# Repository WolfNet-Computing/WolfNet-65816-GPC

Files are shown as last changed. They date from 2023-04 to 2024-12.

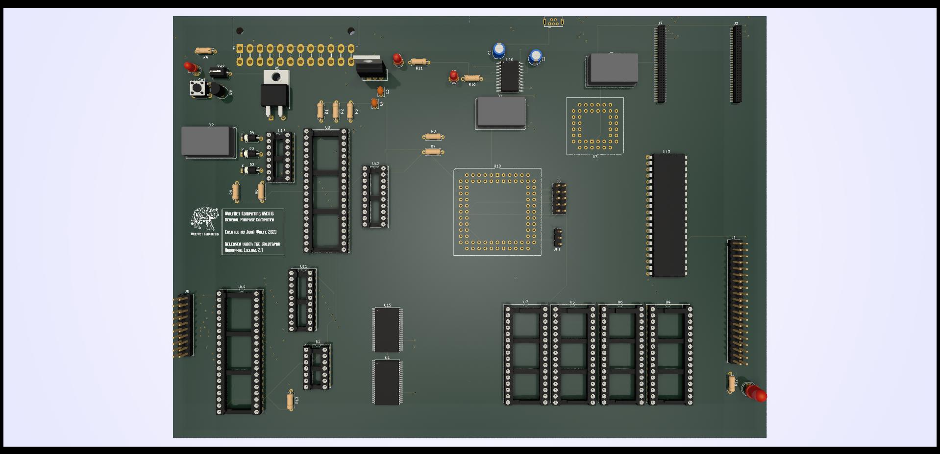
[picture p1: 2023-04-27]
Motherboard.jpg

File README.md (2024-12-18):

# WolfNet-65816-GPC
 WolfNet Computing 65816 based General Purpose Computer

Intended as an upgrade to the WolfNet-65C02-WBC, this computer is more general purpose in design and nature. Text-based USB-Serial control makes connecting to it easy. You don't even need a spare screen or keyboard. Plug it in to your computer, power it on and away you go.

Features:  
 - 65C816 Based design
 - USB Type-B Connnector, MCP2200 and SC28L91 for I/O (Think keyboard, mouse and screen but as a program on your PC, connecting to the device.)
 - ATF1508AS Based Reprogrammable Address Decoder and DMA Controller
 - ATX 20-Pin Power Connector
 - 65-SIB Serial Interface Bus
 - 40-Pin IDE Connector for PATA HDDs
 - 16 MiB Flash ROM
 - 16 MiB SRAM
 - Built-in JTAG-ISP Header for ATF1508AS

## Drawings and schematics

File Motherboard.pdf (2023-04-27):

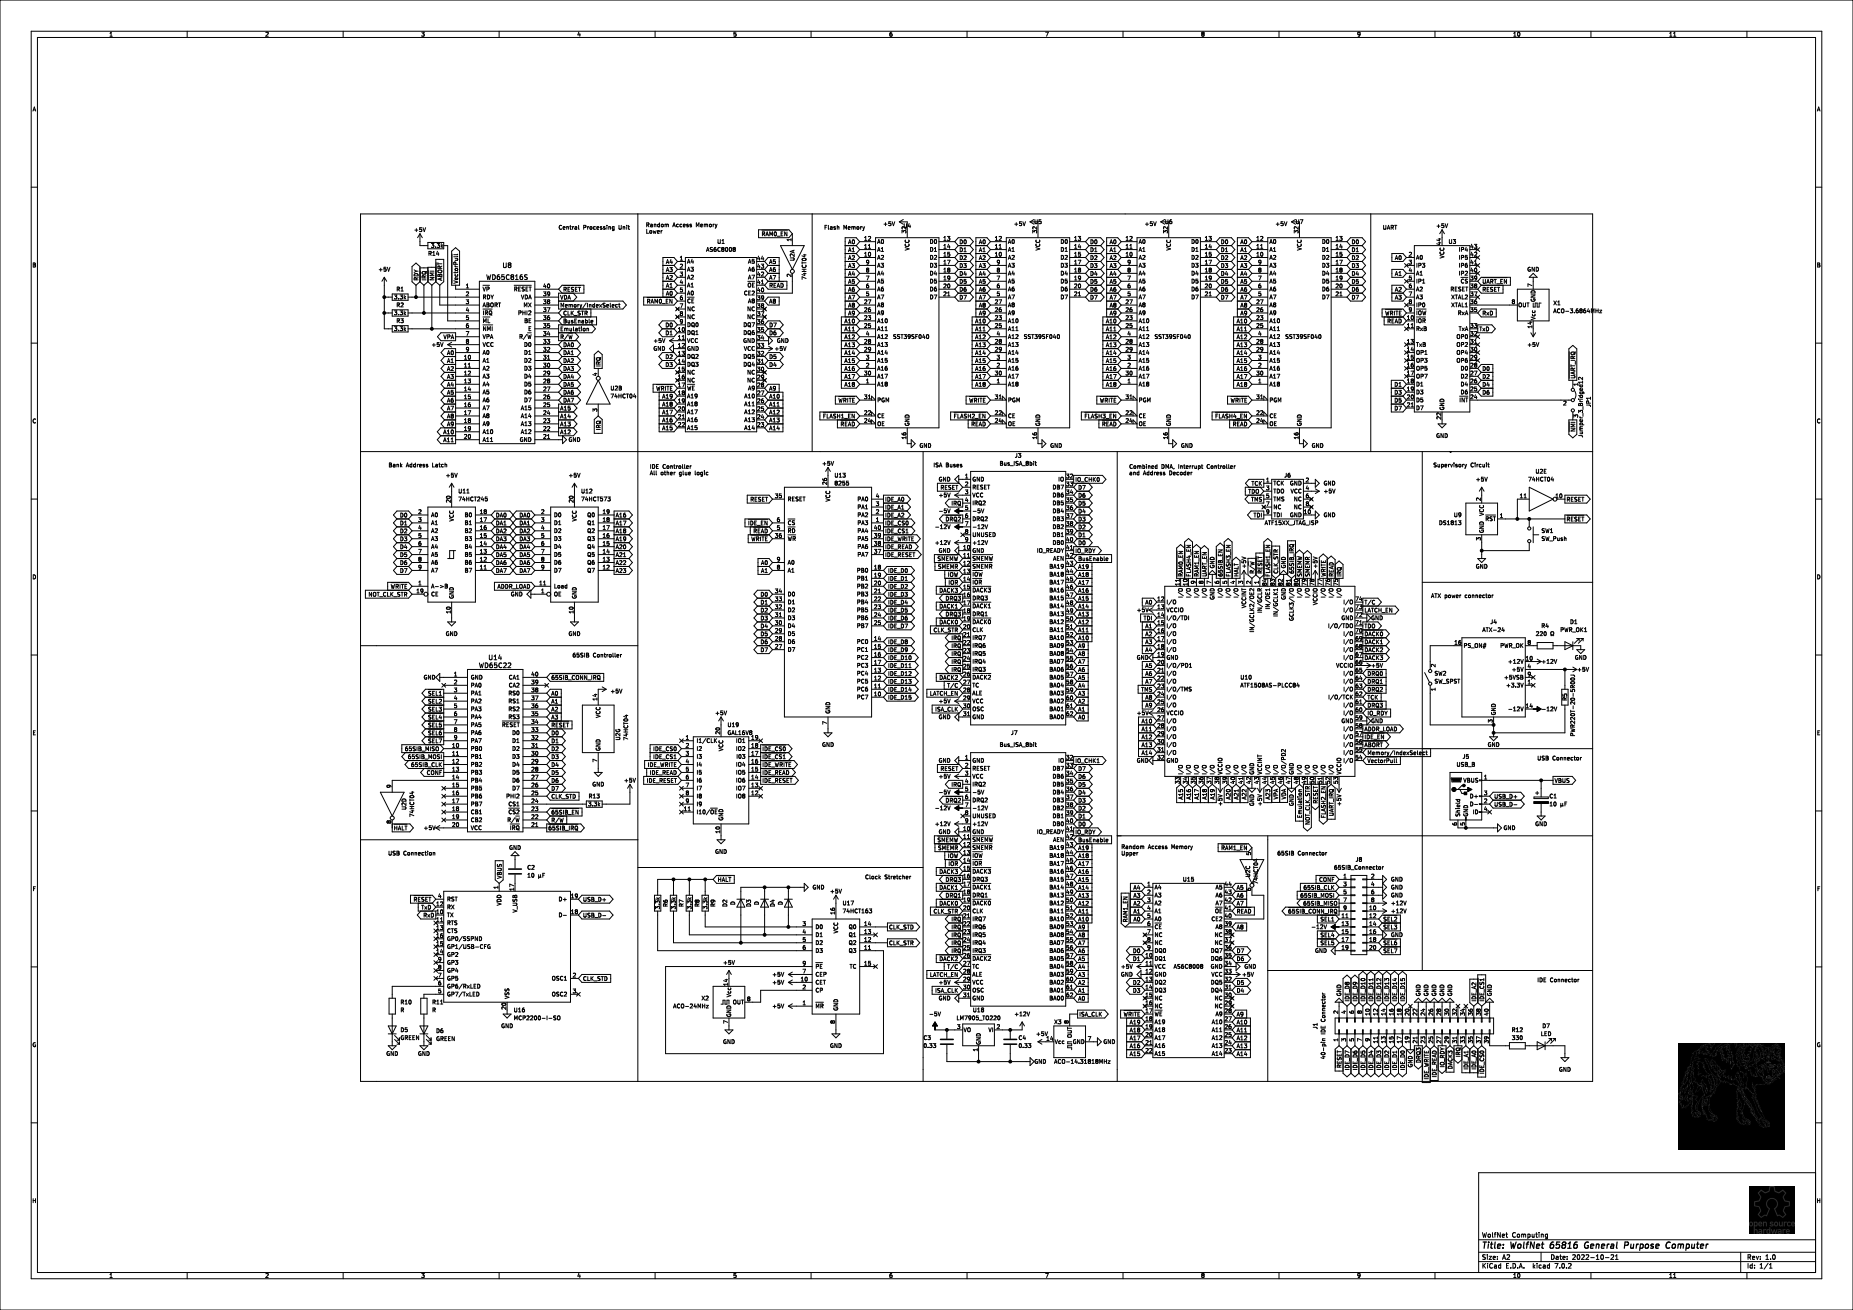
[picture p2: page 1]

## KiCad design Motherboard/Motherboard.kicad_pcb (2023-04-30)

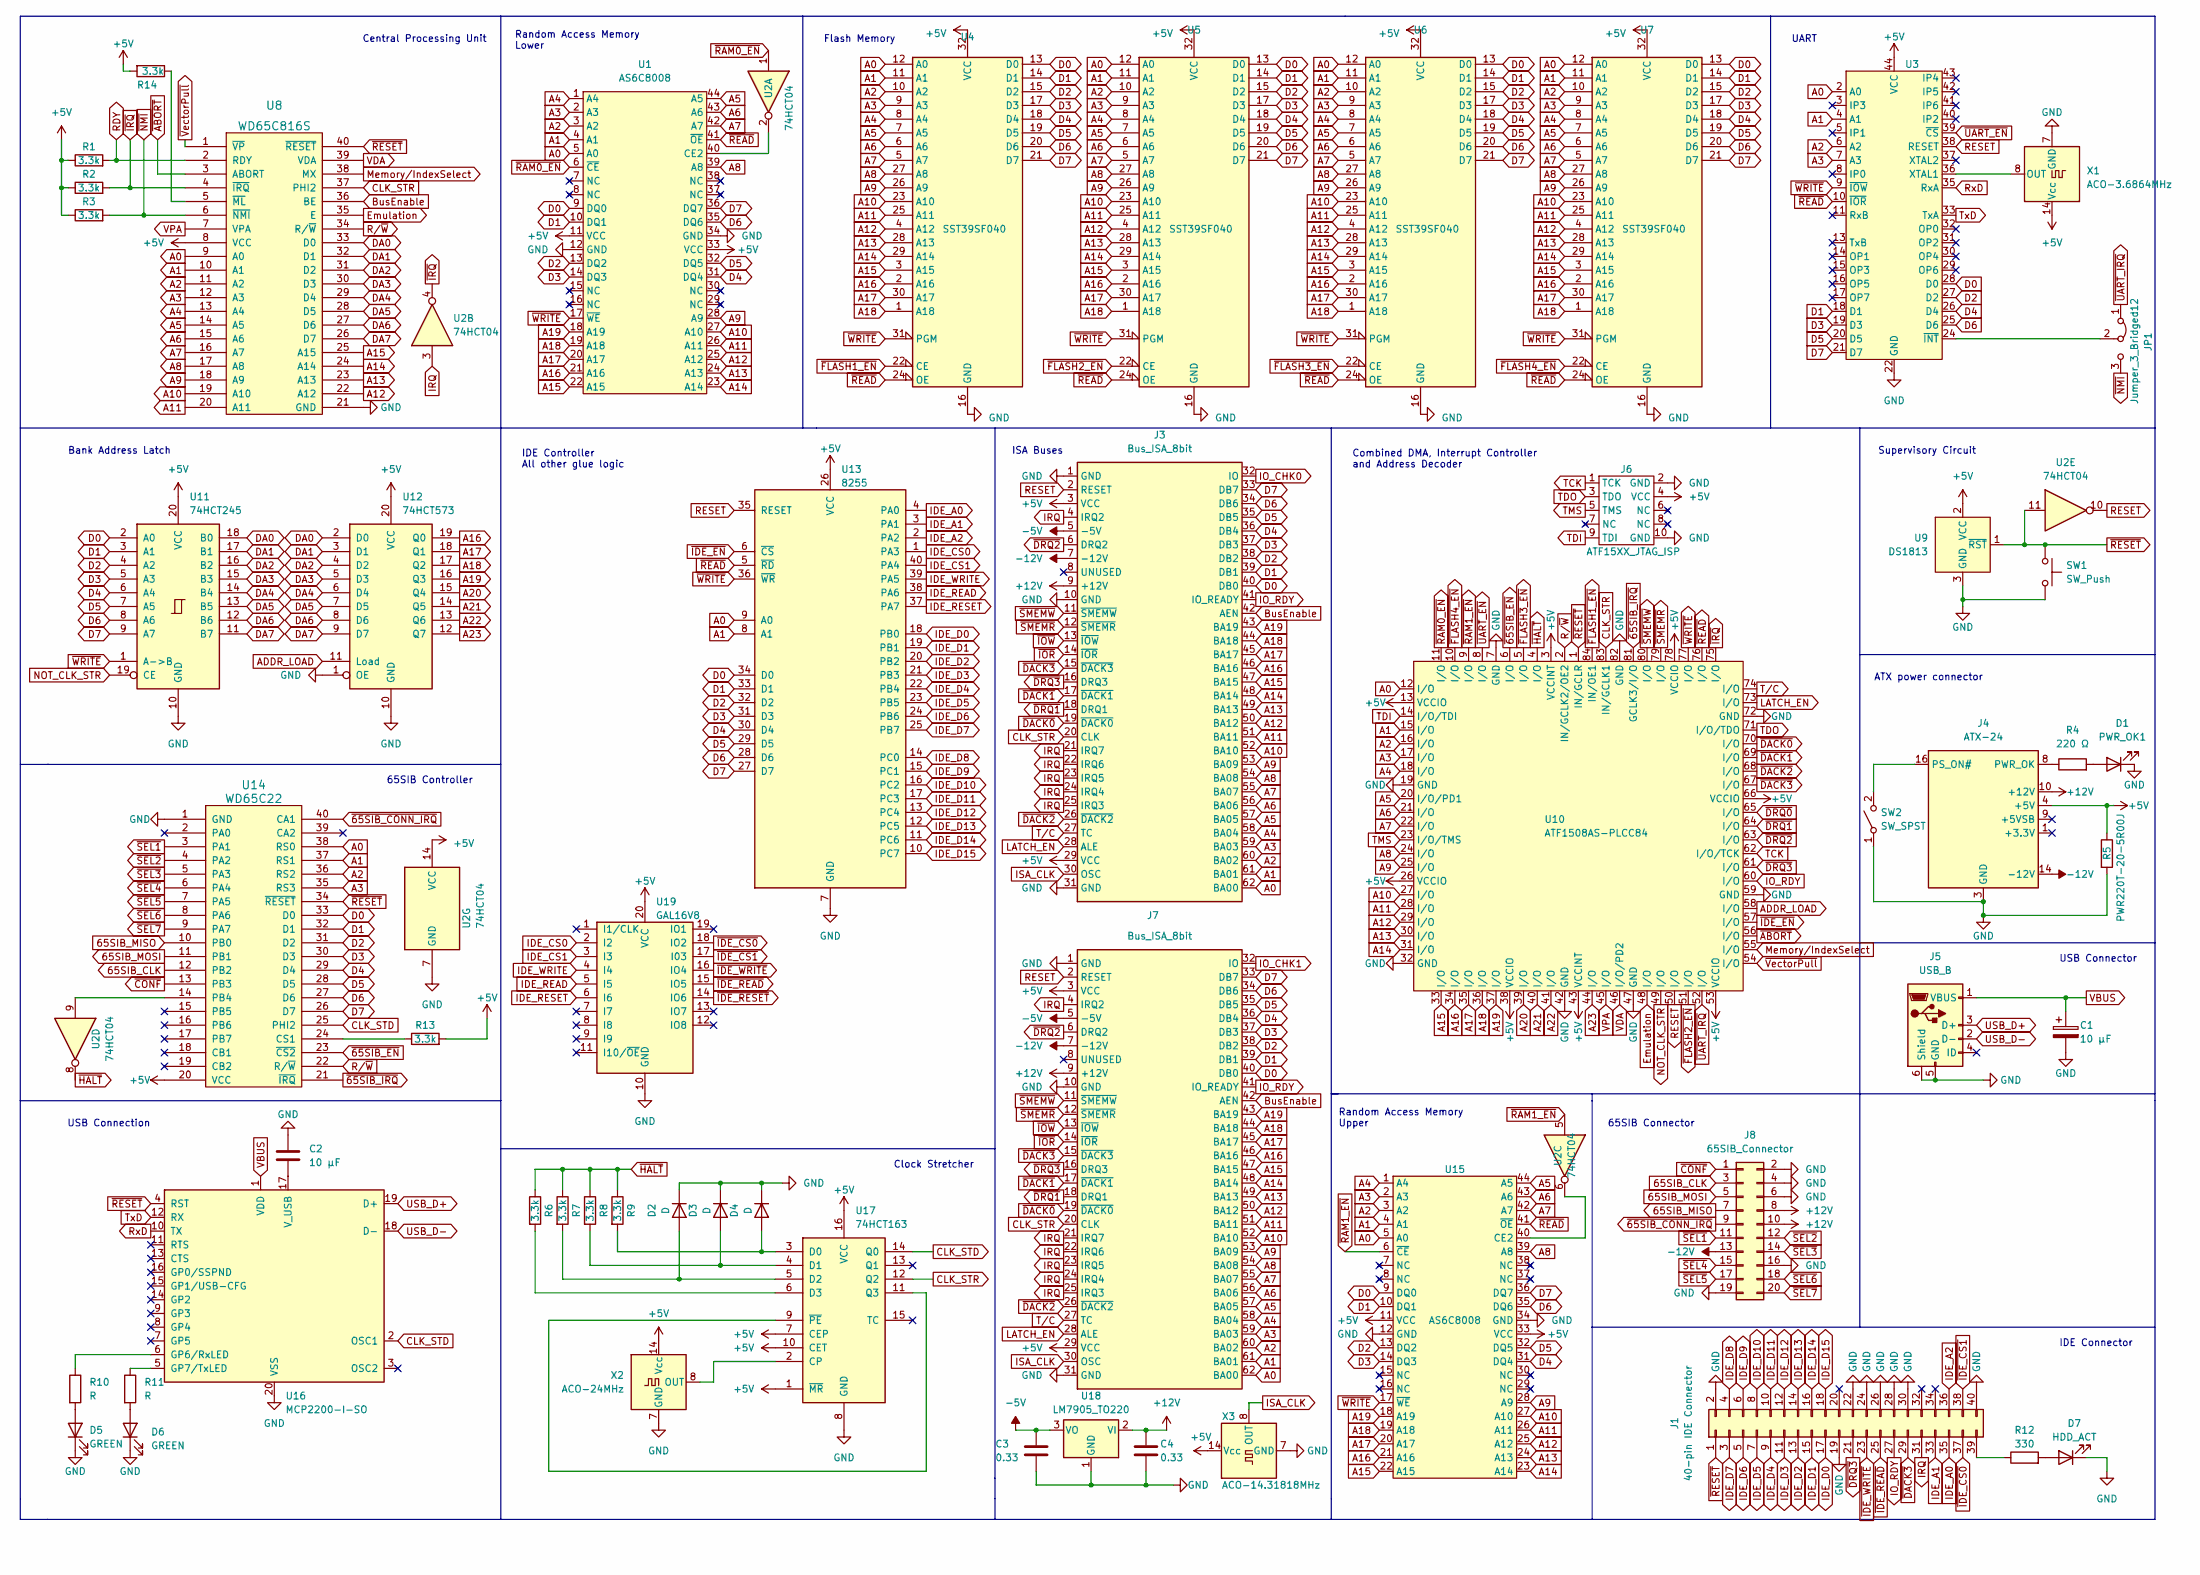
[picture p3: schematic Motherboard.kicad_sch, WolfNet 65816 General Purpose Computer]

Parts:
C1, C2: 10 µF; CP_Radial_D5.0mm_P2.50mm
C3, C4: 0.33; C_Disc_D3.8mm_W2.6mm_P2.50mm
D1: PWR_OK1; LED_D3.0mm
D2, D3, D4: D; D_A-405_P7.62mm_Horizontal
D5, D6: GREEN; LED_D3.0mm
D7: HDD_ACT; LED_D5.0mm
J1: 40-pin IDE Connector; PinHeader_2x20_P2.54mm_Vertical
J3, J7: Bus_ISA_8bit; PinSocket_2x31_P1.00mm_Vertical_SMD
J4: ATX-24; Molex_Mini-Fit_Jr_5569-24A2_2x12_P4.20mm_Horizontal
J5: USB_B; USB_Mini-B_Tensility_54-00023_Vertical
J6: ATF15XX_JTAG_ISP; PinHeader_2x05_P2.54mm_Vertical
J8: 65SIB_Connector; PinHeader_2x10_P2.54mm_Vertical
JP1: Jumper_3_Bridged12; PinHeader_1x03_P2.54mm_Vertical
R1, R2, R3, R6, R7, R8, R9, R13, R14: 3.3k; R_Axial_DIN0207_L6.3mm_D2.5mm_P7.62mm_Horizontal
R4: 220 Ω; R_Axial_DIN0207_L6.3mm_D2.5mm_P7.62mm_Horizontal
R5: PWR220T-20-5R00J; TO-220-2_Horizontal_TabDown
R10, R11: R; R_Axial_DIN0207_L6.3mm_D2.5mm_P7.62mm_Horizontal
R12: 330; R_Axial_DIN0207_L6.3mm_D2.5mm_P7.62mm_Horizontal
SW1: SW_Push; SW_PUSH_6mm
SW2: SW_SPST; SW_DIP_SPSTx01_Slide_6.7x4.1mm_W7.62mm_P2.54mm_LowProfile
U1, U15: AS6C8008; TSOP-II-44_10.16x18.41mm_P0.8mm
U2: 74HCT04; DIP-14_W7.62mm_Socket_LongPads
U3: PLCC-44_THT-Socket
U4, U5, U6, U7: SST39SF040; DIP-32_W15.24mm_Socket_LongPads
U8: WD65C816S; DIP-40_W15.24mm_Socket_LongPads
U9: DS1813; TO-92_Inline
U10: ATF1508AS-PLCC84; PLCC-84_THT-Socket
U11: 74HCT245; DIP-20_W7.62mm_Socket_LongPads
U12: 74HCT573; DIP-20_W7.62mm_Socket_LongPads
U13: 8255; DIP-40_W15.24mm
U14: WD65C22; DIP-40_W15.24mm_Socket_LongPads
U16: MCP2200-I-SO; SOIC-20W_7.5x12.8mm_P1.27mm
U17: 74HCT163; DIP-16_W7.62mm_Socket_LongPads
U18: LM7905_TO220; TO-220-3_Vertical
U19: GAL16V8; DIP-20_W7.62mm_Socket_LongPads
X1: ACO-3.6864MHz; Oscillator_DIP-14
X2: ACO-24MHz; Oscillator_DIP-14
X3: ACO-14.31818MHz; Oscillator_DIP-14

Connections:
65SIB_CLK: J8.3 (CLK), U14.12 (PB2)
65SIB_MISO: J8.7 (MISO), U14.10 (PB0)
65SIB_MOSI: J8.5 (MOSI), U14.11 (PB1)
+5V: J3.3 (VCC), J3.29 (VCC), J4.4 (+5V), J4.6 (+5V), J4.21 (+5V), J4.22 (+5V), J4.23 (+5V), J6.4 (VCC), J7.3 (VCC), J7.29 (VCC), R1.1, R2.1, R3.1, R5.1, R13.2, R14.2, U1.11 (VCC), U1.33 (VCC), U2.14 (VCC), U3.44 (VCC), U4.32 (VCC), U5.32 (VCC), U6.32 (VCC), U7.32 (VCC), U8.8 (VCC), U9.2 (VCC), U10.3 (VCCINT), U10.13 (VCCIO), U10.26 (VCCIO), U10.38 (VCCIO), U10.43 (VCCINT), U10.53 (VCCIO), U10.66 (VCCIO), U10.78 (VCCIO), U11.20 (VCC), U12.20 (VCC), U13.26 (VCC), U14.20 (VCC), U15.11 (VCC), U15.33 (VCC), U17.1 (~MR), U17.7 (CEP), U17.10 (CET), U17.16 (VCC), U19.20 (VCC), X1.14 (Vcc), X2.14 (Vcc), X3.14 (Vcc)
+12V: C4.1, J3.9 (+12V), J4.10 (+12V), J4.11 (+12V), J7.9 (+12V), J8.8 (12v), J8.10 (12v), U18.2 (VI)
-5V: C3.1, J3.5 (-5V), J7.5 (-5V), U18.3 (VO)
-12V: J3.7 (-12V), J4.14 (-12V), J7.7 (-12V), J8.13 (-12v)
A0: J3.62 (BA00), J7.62 (BA00), U1.5 (A0), U3.2 (A0), U4.12 (A0), U5.12 (A0), U6.12 (A0), U7.12 (A0), U8.9 (A0), U10.12 (I/O), U13.9 (A0), U14.38 (RS0), U15.5 (A0)
A1: J3.61 (BA01), J7.61 (BA01), U1.4 (A1), U3.4 (A1), U4.11 (A1), U5.11 (A1), U6.11 (A1), U7.11 (A1), U8.10 (A1), U10.15 (I/O), U13.8 (A1), U14.37 (RS1), U15.4 (A1)
A2: J3.60 (BA02), J7.60 (BA02), U1.3 (A2), U3.6 (A2), U4.10 (A2), U5.10 (A2), U6.10 (A2), U7.10 (A2), U8.11 (A2), U10.16 (I/O), U14.36 (RS2), U15.3 (A2)
A3: J3.59 (BA03), J7.59 (BA03), U1.2 (A3), U3.7 (A3), U4.9 (A3), U5.9 (A3), U6.9 (A3), U7.9 (A3), U8.12 (A3), U10.17 (I/O), U14.35 (RS3), U15.2 (A3)
A4: J3.58 (BA04), J7.58 (BA04), U1.1 (A4), U4.8 (A4), U5.8 (A4), U6.8 (A4), U7.8 (A4), U8.13 (A4), U10.18 (I/O), U15.1 (A4)
A5: J3.57 (BA05), J7.57 (BA05), U1.44 (A5), U4.7 (A5), U5.7 (A5), U6.7 (A5), U7.7 (A5), U8.14 (A5), U10.20 (I/O/PD1), U15.44 (A5)
A6: J3.56 (BA06), J7.56 (BA06), U1.43 (A6), U4.6 (A6), U5.6 (A6), U6.6 (A6), U7.6 (A6), U8.15 (A6), U10.21 (I/O), U15.43 (A6)
A7: J3.55 (BA07), J7.55 (BA07), U1.42 (A7), U4.5 (A7), U5.5 (A7), U6.5 (A7), U7.5 (A7), U8.16 (A7), U10.22 (I/O), U15.42 (A7)
A8: J3.54 (BA08), J7.54 (BA08), U1.39 (A8), U4.27 (A8), U5.27 (A8), U6.27 (A8), U7.27 (A8), U8.17 (A8), U10.24 (I/O), U15.39 (A8)
A9: J3.53 (BA09), J7.53 (BA09), U1.28 (A9), U4.26 (A9), U5.26 (A9), U6.26 (A9), U7.26 (A9), U8.18 (A9), U10.25 (I/O), U15.28 (A9)
A10: J3.52 (BA10), J7.52 (BA10), U1.27 (A10), U4.23 (A10), U5.23 (A10), U6.23 (A10), U7.23 (A10), U8.19 (A10), U10.27 (I/O), U15.27 (A10)
A11: J3.51 (BA11), J7.51 (BA11), U1.26 (A11), U4.25 (A11), U5.25 (A11), U6.25 (A11), U7.25 (A11), U8.20 (A11), U10.28 (I/O), U15.26 (A11)
A12: J3.50 (BA12), J7.50 (BA12), U1.25 (A12), U4.4 (A12), U5.4 (A12), U6.4 (A12), U7.4 (A12), U8.22 (A12), U10.29 (I/O), U15.25 (A12)
A13: J3.49 (BA13), J7.49 (BA13), U1.24 (A13), U4.28 (A13), U5.28 (A13), U6.28 (A13), U7.28 (A13), U8.23 (A13), U10.30 (I/O), U15.24 (A13)
A14: J3.48 (BA14), J7.48 (BA14), U1.23 (A14), U4.29 (A14), U5.29 (A14), U6.29 (A14), U7.29 (A14), U8.24 (A14), U10.31 (I/O), U15.23 (A14)
A15: J3.47 (BA15), J7.47 (BA15), U1.22 (A15), U4.3 (A15), U5.3 (A15), U6.3 (A15), U7.3 (A15), U8.25 (A15), U10.33 (I/O), U15.22 (A15)
A16: J3.46 (BA16), J7.46 (BA16), U1.21 (A16), U4.2 (A16), U5.2 (A16), U6.2 (A16), U7.2 (A16), U10.34 (I/O), U12.19 (Q0), U15.21 (A16)
A17: J3.45 (BA17), J7.45 (BA17), U1.20 (A17), U4.30 (A17), U5.30 (A17), U6.30 (A17), U7.30 (A17), U10.35 (I/O), U12.18 (Q1), U15.20 (A17)
A18: J3.44 (BA18), J7.44 (BA18), U1.19 (A18), U4.1 (A18), U5.1 (A18), U6.1 (A18), U7.1 (A18), U10.36 (I/O), U12.17 (Q2), U15.19 (A18)
A19: J3.43 (BA19), J7.43 (BA19), U1.18 (A19), U10.37 (I/O), U12.16 (Q3), U15.18 (A19)
A20: U10.39 (I/O), U12.15 (Q4)
A21: U10.40 (I/O), U12.14 (Q5)
A22: U10.41 (I/O), U12.13 (Q6)
A23: U10.44 (I/O), U12.12 (Q7)
ADDR_LOAD: U10.58 (I/O), U12.11 (Load)
BusEnable: J3.42 (AEN), J7.42 (AEN), U8.36 (BE)
CLK_STD: U14.25 (PHI2), U16.2 (OSC1), U17.14 (Q0)
CLK_STR: J3.20 (CLK), J7.20 (CLK), U8.37 (PHI2), U10.83 (IN/GCLK1), U17.12 (Q2)
D0: J3.40 (DB0), J7.40 (DB0), U1.9 (DQ0), U3.28 (D0), U4.13 (D0), U5.13 (D0), U6.13 (D0), U7.13 (D0), U11.2 (A0), U13.34 (D0), U14.33 (D0), U15.9 (DQ0)
D1: J3.39 (DB1), J7.39 (DB1), U1.10 (DQ1), U3.18 (D1), U4.14 (D1), U5.14 (D1), U6.14 (D1), U7.14 (D1), U11.3 (A1), U13.33 (D1), U14.32 (D1), U15.10 (DQ1)
D2: J3.38 (DB2), J7.38 (DB2), U1.13 (DQ2), U3.27 (D2), U4.15 (D2), U5.15 (D2), U6.15 (D2), U7.15 (D2), U11.4 (A2), U13.32 (D2), U14.31 (D2), U15.13 (DQ2)
D3: J3.37 (DB3), J7.37 (DB3), U1.14 (DQ3), U3.19 (D3), U4.17 (D3), U5.17 (D3), U6.17 (D3), U7.17 (D3), U11.5 (A3), U13.31 (D3), U14.30 (D3), U15.14 (DQ3)
D4: J3.36 (DB4), J7.36 (DB4), U1.31 (DQ4), U3.26 (D4), U4.18 (D4), U5.18 (D4), U6.18 (D4), U7.18 (D4), U11.6 (A4), U13.30 (D4), U14.29 (D4), U15.31 (DQ4)
D5: J3.35 (DB5), J7.35 (DB5), U1.32 (DQ5), U3.20 (D5), U4.19 (D5), U5.19 (D5), U6.19 (D5), U7.19 (D5), U11.7 (A5), U13.29 (D5), U14.28 (D5), U15.32 (DQ5)
D6: J3.34 (DB6), J7.34 (DB6), U1.35 (DQ6), U3.25 (D6), U4.20 (D6), U5.20 (D6), U6.20 (D6), U7.20 (D6), U11.8 (A6), U13.28 (D6), U14.27 (D6), U15.35 (DQ6)
D7: J3.33 (DB7), J7.33 (DB7), U1.36 (DQ7), U3.21 (D7), U4.21 (D7), U5.21 (D7), U6.21 (D7), U7.21 (D7), U11.9 (A7), U13.27 (D7), U14.26 (D7), U15.36 (DQ7)
DA0: U8.33 (D0), U11.18 (B0), U12.2 (D0)
DA1: U8.32 (D1), U11.17 (B1), U12.3 (D1)
DA2: U8.31 (D2), U11.16 (B2), U12.4 (D2)
DA3: U8.30 (D3), U11.15 (B3), U12.5 (D3)
DA4: U8.29 (D4), U11.14 (B4), U12.6 (D4)
DA5: U8.28 (D5), U11.13 (B5), U12.7 (D5)
DA6: U8.27 (D6), U11.12 (B6), U12.8 (D6)
DA7: U8.26 (D7), U11.11 (B7), U12.9 (D7)
Emulation: U8.35 (E), U10.48 (I/O)
GND: C1.2, C2.1, C3.2, C4.2, D1.1 (K), D2.1 (K), D3.1 (K), D4.1 (K), D5.1 (K), D6.1 (K), D7.1 (K), J1.2, J1.19, J1.22, J1.24, J1.26, J1.28, J1.30, J1.40, J3.1 (GND), J3.10 (GND), J3.31 (GND), J4.3 (GND), J4.5 (GND), J4.7 (GND), J4.15 (GND), J4.17 (GND), J4.18 (GND), J4.19 (GND), J4.24 (GND), J5.5 (GND), J5.6 (Shield), J6.2 (GND), J6.10 (GND), J7.1 (GND), J7.10 (GND), J7.31 (GND), J8.2 (GND), J8.4 (GND), J8.6 (eGND), J8.16 (GND), J8.19 (GND), R5.2, SW1.2, SW2.1 (A), U1.12 (GND), U1.34 (GND), U2.7 (GND), U3.22 (GND), U4.16 (GND), U5.16 (GND), U6.16 (GND), U7.16 (GND), U8.21 (GND), U9.3 (GND), U10.7 (GND), U10.19 (GND), U10.32 (GND), U10.42 (GND), U10.47 (GND), U10.59 (GND), U10.72 (GND), U10.82 (GND), U11.10 (GND), U12.1 (OE), U12.10 (GND), U13.7 (GND), U14.1 (GND), U15.12 (GND), U15.34 (GND), U16.20 (VSS), U17.8 (GND), U18.1 (GND), U19.10 (GND), X1.7 (GND), X2.7 (GND), X3.7 (GND)
IDE_A0: J1.35, U13.4 (PA0)
IDE_A1: J1.33, U13.3 (PA1)
IDE_A2: J1.36, U13.2 (PA2)
IDE_CS0: U13.1 (PA3), U19.2 (I2)
IDE_CS1: U13.40 (PA4), U19.3 (I3)
IDE_D0: J1.17, U13.18 (PB0)
IDE_D1: J1.15, U13.19 (PB1)
IDE_D2: J1.13, U13.20 (PB2)
IDE_D3: J1.11, U13.21 (PB3)
IDE_D4: J1.9, U13.22 (PB4)
IDE_D5: J1.7, U13.23 (PB5)
IDE_D6: J1.5, U13.24 (PB6)
IDE_D7: J1.3, U13.25 (PB7)
IDE_D8: J1.4, U13.14 (PC0)
IDE_D9: J1.6, U13.15 (PC1)
IDE_D10: J1.8, U13.16 (PC2)
IDE_D11: J1.10, U13.17 (PC3)
IDE_D12: J1.12, U13.13 (PC4)
IDE_D13: J1.14, U13.12 (PC5)
IDE_D14: J1.16, U13.11 (PC6)
IDE_D15: J1.18, U13.10 (PC7)
IDE_READ: U13.38 (PA6), U19.5 (I5)
IDE_RESET: U13.37 (PA7), U19.6 (I6)
IDE_WRITE: U13.39 (PA5), U19.4 (I4)
IO_CHK0: J3.32 (IO)
IO_CHK1: J7.32 (IO)
IO_RDY: J1.27, J3.41 (IO_READY), J7.41 (IO_READY), U10.60 (I/O)
IRQ: J1.31, J3.4 (IRQ2), J3.21 (IRQ7), J3.22 (IRQ6), J3.23 (IRQ5), J3.24 (IRQ4), J3.25 (IRQ3), J7.4 (IRQ2), J7.21 (IRQ7), J7.22 (IRQ6), J7.23 (IRQ5), J7.24 (IRQ4), J7.25 (IRQ3), U2.3
ISA_CLK: J3.30 (OSC), J7.30 (OSC), X3.8 (OUT)
LATCH_EN: J3.28 (ALE), J7.28 (ALE), U10.73 (I/O)
Memory/IndexSelect: U8.38 (MX), U10.55 (I/O)
NOT_CLK_STR: U10.49 (I/O), U11.19 (CE)
unnamed: D1.2 (A), R4.2
unnamed: D2.2 (A), R7.2, U17.5 (D2)
unnamed: D3.2 (A), R8.2, U17.4 (D1)
unnamed: D4.2 (A), R9.2, U17.3 (D0)
unnamed: D5.2 (A), R10.2
unnamed: D6.2 (A), R11.2
unnamed: D7.2 (A), R12.2
unnamed: J1.39, R12.1
unnamed: J4.16 (PS_ON#), SW2.2 (B)
unnamed: J4.8 (PWR_OK), R4.1
unnamed: JP1.2 (C), U3.24 (~INT)
unnamed: U1.40 (CE2), U2.2
unnamed: U3.36 (XTAL1), X1.8 (OUT)
unnamed: R14.1, U8.5 (~ML)
unnamed: R13.1, U14.24 (CS1)
unnamed: U2.9, U14.14 (PB4)
unnamed: U2.6, U15.40 (CE2)
unnamed: R10.1, U16.6 (GP6/RxLED)
unnamed: R11.1, U16.5 (GP7/TxLED)
unnamed: C2.2, U16.17 (V_USB)
unnamed: U17.2 (CP), X2.8 (OUT)
unnamed: R6.2, U17.6 (D3)
unnamed: U17.9 (~PE), U17.11 (Q3)
RDY: R1.2, U8.2 (RDY)
RESET: J3.2 (RESET), J7.2 (RESET), U2.10, U3.38 (RESET), U10.50 (I/O), U13.35 (RESET)
RxD: U3.35 (RxA), U16.10 (TX)
R/~W: U8.34 (R/~W), U10.2 (IN/GCLK2/OE2), U14.22 (R/~W)
TCK: J6.1 (TCK), U10.62 (I/O/TCK)
TDI: J6.9 (TDI), U10.14 (I/O/TDI)
TDO: J6.3 (TDO), U10.71 (I/O/TDO)
TMS: J6.5 (TMS), U10.23 (I/O/TMS)
TxD: U3.33 (TxA), U16.12 (RX)
T/C: J3.27 (TC), J7.27 (TC), U10.74 (I/O)
USB_D+: J5.3 (D+), U16.19 (D+)
USB_D-: J5.2 (D-), U16.18 (D-)
VBUS: C1.1, J5.1 (VBUS), U16.1 (VDD)
VDA: U8.39 (VDA), U10.46 (I/O/PD2)
VPA: U8.7 (VPA), U10.45 (I/O)
~65SIB_CONN_IRQ: J8.9 (IRO\), U14.40 (CA1)
~65SIB_EN: U10.6 (I/O), U14.23 (~CS2)
~65SIB_IRQ: U10.81 (GCLK3/I/O), U14.21 (~IRQ)
~ABORT: U8.3 (ABORT), U10.56 (I/O)
~CONF: J8.1 (CONF\), U14.13 (PB3)
~DACK0: J3.19 (~DACK0), J7.19 (~DACK0), U10.70 (I/O)
~DACK1: J3.17 (~DACK1), J7.17 (~DACK1), U10.69 (I/O)
~DACK2: J3.26 (~DACK2), J7.26 (~DACK2), U10.68 (I/O)
~DACK3: J1.29, J3.15 (~DACK3), J7.15 (~DACK3), U10.67 (I/O)
~DRQ0: U10.65 (I/O)
~DRQ1: J3.18 (DRQ1), J7.18 (DRQ1), U10.64 (I/O)
~DRQ2: J3.6 (DRQ2), J7.6 (DRQ2), U10.63 (I/O)
~DRQ3: J1.21, J3.16 (DRQ3), J7.16 (DRQ3), U10.61 (I/O)
~FLASH1_EN: U4.22 (CE), U10.84 (IN/OE1)
~FLASH2_EN: U5.22 (CE), U10.51 (I/O)
~FLASH3_EN: U6.22 (CE), U10.5 (I/O)
~FLASH4_EN: U7.22 (CE), U10.10 (I/O)
~HALT: R6.1, R7.1, R8.1, R9.1, U2.8, U10.4 (I/O)
~IDE_CS0: J1.37, U19.18 (IO2)
~IDE_CS1: J1.38, U19.17 (I03)
~IDE_EN: U10.57 (I/O), U13.6 (~CS)
~IDE_READ: J1.25, U19.15 (IO5)
~IDE_RESET: U19.14 (IO6)
~IDE_WRITE: J1.23, U19.16 (IO4)
~IOR: J3.14 (~IOR), J7.14 (~IOR)
~IOW: J3.13 (~IOW), J7.13 (~IOW)
~IRQ: R2.2, U2.4, U8.4 (~IRQ), U10.75 (I/O)
~NMI: JP1.3 (B), R3.2, U8.6 (~NMI)
~RAM0_EN: U1.6 (~CE), U2.1, U10.11 (I/O)
~RAM1_EN: U2.5, U10.9 (I/O), U15.6 (~CE)
~READ: U1.41 (~OE), U3.10 (~IOR), U4.24 (OE), U5.24 (OE), U6.24 (OE), U7.24 (OE), U10.76 (I/O), U13.5 (~RD), U15.41 (~OE)
~RESET: J1.1, SW1.1, U2.11, U8.40 (~RESET), U9.1 (~RST), U10.1 (IN/GCLR), U14.34 (~RESET), U16.4 (RST)
~SEL1: J8.11 (SEL1\), U14.3 (PA1)
~SEL2: J8.12 (SEL2\), U14.4 (PA2)
~SEL3: J8.14 (SEL3\), U14.5 (PA3)
~SEL4: J8.15 (SEL4\), U14.6 (PA4)
~SEL5: J8.17 (SEL5\), U14.7 (PA5)
~SEL6: J8.18 (SEL6\), U14.8 (PA6)
~SEL7: J8.20 (SEL7\), U14.9 (PA7)
~SMEMR: J3.12 (~SMEMR), J7.12 (~SMEMR), U10.79 (I/O)
~SMEMW: J3.11 (~SMEMW), J7.11 (~SMEMW), U10.80 (I/O)
~UART_EN: U3.39 (~CS), U10.8 (I/O)
~UART_IRQ: JP1.1 (A), U10.52 (I/O)
~VectorPull: U8.1 (~VP), U10.54 (I/O)
~WRITE: U1.17 (~WE), U3.9 (~IOW), U4.31 (PGM), U5.31 (PGM), U6.31 (PGM), U7.31 (PGM), U10.77 (I/O), U11.1 (A->B), U13.36 (~WR), U15.17 (~WE)

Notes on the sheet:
IDE Controller All other glue logic
Flash Memory
ISA Buses
USB Connector
Central Processing Unit
ATX power connector
IDE Connector
Supervisory Circuit
Combined DMA, Interrupt Controller and Address Decoder
65SIB Controller
Clock Stretcher
UART
USB Connection
Random Access Memory Lower
Random Access Memory Upper
Bank Address Latch
65SIB Connector

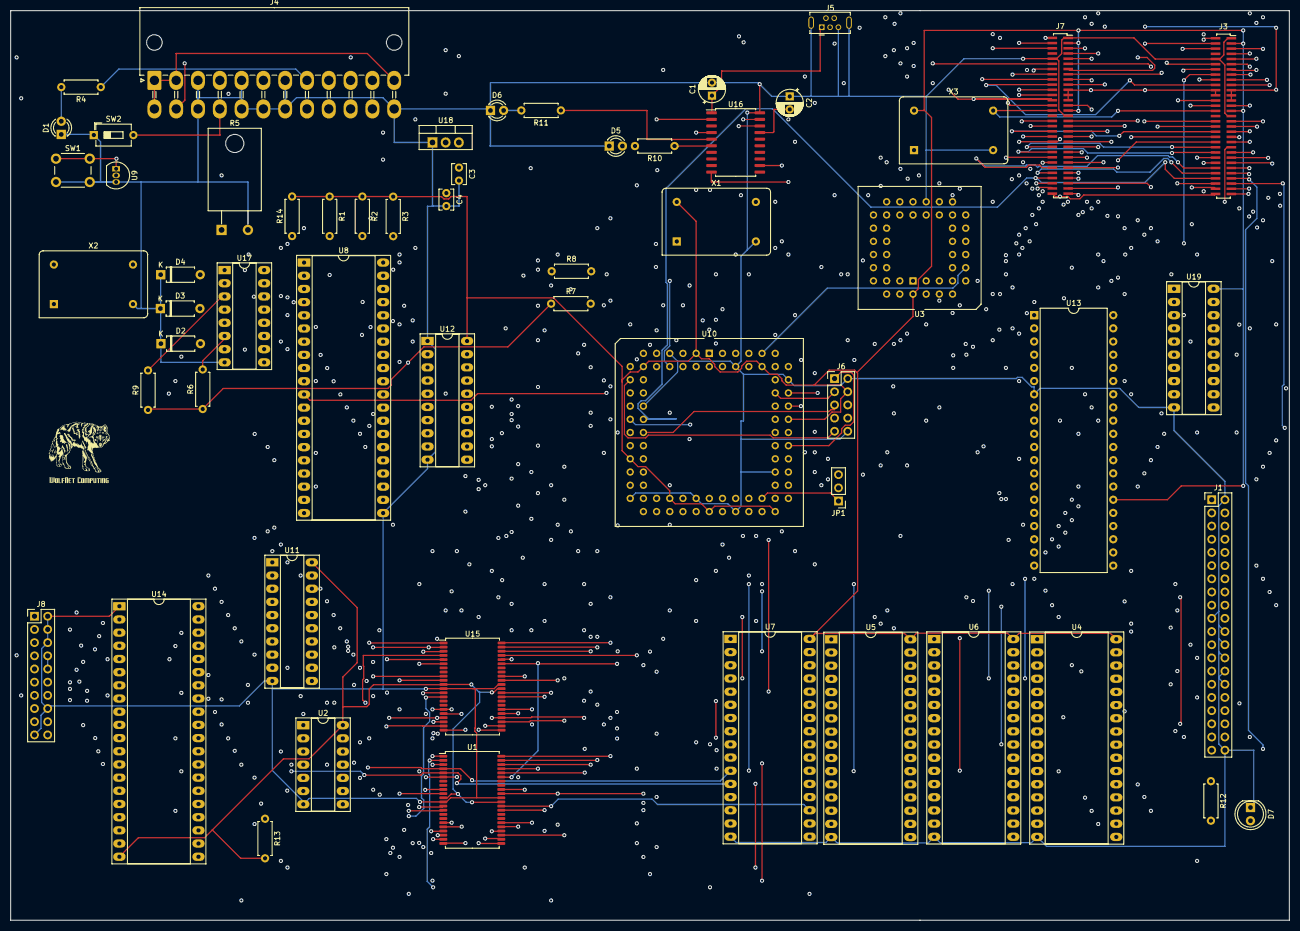
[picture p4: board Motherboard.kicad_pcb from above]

Board: 4 copper layers, 246.4 x 175.3 mm, 57 parts (0 on the bottom side), 164 nets.

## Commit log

2022-10-21 First upload from Git...
    [WolfNet-65816-GPC.kicad_pcb, WolfNet-65816-GPC.kicad_sch]
2022-10-21 Added and connected CPU...
    [WolfNet-65816-GPC.kicad_sch]
2022-10-21 Added and connected RAM...
    [WolfNet-65816-GPC.kicad_sch]
2022-10-22 Added and connected 2 ROM Banks...
    [WolfNet-65816-GPC.kicad_sch]
2022-10-24 Almost there...
    [WolfNet-65816-GPC.kicad_sch]
2022-10-25 Changing ROM to Flash memory...
    [WolfNet-65816-GPC.kicad_sch]
2022-10-26 Replaced ROM with Flash memory...
    [WolfNet-65816-GPC.kicad_sch]
2022-10-27 Create WolfNet-65816-GPC.kicad_sch-bak
2022-10-29 Connected ISA ports...
    [WolfNet-65816-GPC.kicad_sch]
2022-10-29 Migrated files to Motherboard subfolder...
    [Motherboard.kicad_pcb, Motherboard.kicad_sch]
2022-10-30 Finished schematic for address decoding...
    [Motherboard.kicad_sch]
2023-03-20 Started on PCB layout...
    [Motherboard.kicad_pcb, Motherboard.kicad_sch]
2023-03-21 More on the road to 2.0
    [Motherboard.kicad_pcb, Motherboard.kicad_sch]
2023-03-26 On the road to 1.0...
    [Motherboard.kicad_pcb, Motherboard.kicad_sch]
2023-03-30 Motherboard PCB updated...
    [Motherboard.kicad_pcb]
2023-04-18 Added traces...
    [Motherboard.kicad_pcb]
2023-04-20 Added IDE controller and fixed HALT signal...
    [Motherboard.kicad_pcb, Motherboard.kicad_sch]
2023-04-21 Update IDE Interface, controller and added parts to PCB...
    [Motherboard.kicad_pcb, Motherboard.kicad_sch]
2023-04-21 477 unrouted traces...
    [Motherboard.kicad_pcb]
2023-04-21 475 unrouted traces...
    [Motherboard.kicad_pcb]
2023-04-21 472 unrouted traces...
    [Motherboard.kicad_pcb]
2023-04-21 443 unrouted traces...
    [Motherboard.kicad_pcb]
2023-04-21 354 unrouted traces...
    [Motherboard.kicad_pcb]
2023-04-22 350 unrouted traces...
    [Motherboard.kicad_pcb]
2023-04-22 Fixed clock connections...
    [Motherboard.kicad_pcb, Motherboard.kicad_sch]
2023-04-22 340 unrouted traces...
    [Motherboard.kicad_pcb]
2023-04-22 334 unrouted traces...
    [Motherboard.kicad_pcb]
2023-04-24 Replaced discontinued DUART and fixed wiring...
    [Motherboard.kicad_sch]
2023-04-24 Updated component footprints...
    [Motherboard.kicad_sch]
2023-04-24 343 unrouted traces...
    [Motherboard.kicad_pcb]
2023-04-24 Fixed D7 line...
    [Motherboard.kicad_sch]
2023-04-24 337 unrouted traces...
    [Motherboard.kicad_pcb]
2023-04-24 332 unrouted traces...
    [Motherboard.kicad_pcb]
2023-04-24 325 unrouted traces...
    [Motherboard.kicad_pcb]
2023-04-24 316 unrouted traces...
    [Motherboard.kicad_pcb, Motherboard.kicad_sch]
2023-04-27 307 unrouted traces...
    [Motherboard.kicad_pcb]
2023-04-28 305 unrouted traces...
    [Motherboard.kicad_pcb]
2023-04-28 300 unrouted traces...
    [Motherboard.kicad_pcb]
2023-04-28 288 unrouted traces...
    [Motherboard.kicad_pcb]
2023-04-28 268 unrouted traces...
    [Motherboard.kicad_pcb]
2023-04-28 265 unrouted traces...
    [Motherboard.kicad_pcb]
2023-04-29 260 unrouted traces...
    [Motherboard.kicad_pcb]
2023-04-29 230 unrouted traces...
    [Motherboard.kicad_pcb]
2023-04-29 226 unrouted traces...
    [Motherboard.kicad_pcb]
2023-04-29 222 unrouted traces...
    [Motherboard.kicad_pcb]
2023-04-29 200 unrouted traces...
    [Motherboard.kicad_pcb]
2023-04-29 190 unrouted traces...
    [Motherboard.kicad_pcb]
2023-04-29 180 unrouted traces...
    [Motherboard.kicad_pcb]
2023-04-29 176 unrouted traces...
    [Motherboard.kicad_pcb]
2023-04-29 173 unrouted traces...
    [Motherboard.kicad_pcb]
2023-04-29 150 Unrouted traces...
    [Motherboard.kicad_pcb]
2023-04-29 134 Unrouted traces...
    [Motherboard.kicad_pcb]
2023-04-29 118 Unrouted traces...
    [Motherboard.kicad_pcb]
2023-04-29 110 Unrouted traces...
    [Motherboard.kicad_pcb]
2023-04-29 103 Unrouted traces...
    [Motherboard.kicad_pcb]
2023-04-30 98 Unrouted traces...
    [Motherboard.kicad_pcb]
2023-04-30 92 Unrouted traces...
    [Motherboard.kicad_pcb]
2023-04-30 Fixed DRQ1 line...
    [Motherboard.kicad_sch]
2023-04-30 86 Unrouted traces...
    [Motherboard.kicad_pcb]
2023-04-30 80 Unrouted traces...
    [Motherboard.kicad_pcb]
2023-04-30 72 Unrouted traces...
    [Motherboard.kicad_pcb]
2023-04-30 69 Unrouted traces...
    [Motherboard.kicad_pcb]
2023-04-30 64 Unrouted traces...
    [Motherboard.kicad_pcb]
2023-04-30 54 Unrouted traces...
    [Motherboard.kicad_pcb]
2023-04-30 36 Unrouted traces...
    [Motherboard.kicad_pcb]
2023-04-30 10 Unrouted traces...
    [Motherboard.kicad_pcb]
2023-04-30 Routing Complete...
    [Motherboard.kicad_pcb]

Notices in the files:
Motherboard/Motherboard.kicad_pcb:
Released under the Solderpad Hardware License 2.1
